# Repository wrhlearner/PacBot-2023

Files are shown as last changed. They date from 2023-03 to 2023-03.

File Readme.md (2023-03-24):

# **Schedule**

## **Directions**

- Hardware: 
  - Axel: Teensy4.0, Magnetic encoder, Motor driver, Motor
  - Jack: RaspberryPi, Motor driver, IR sensors
- Software: 
  - Ines: Server side
  - Jack: GameEngine host side and RaspberryPi

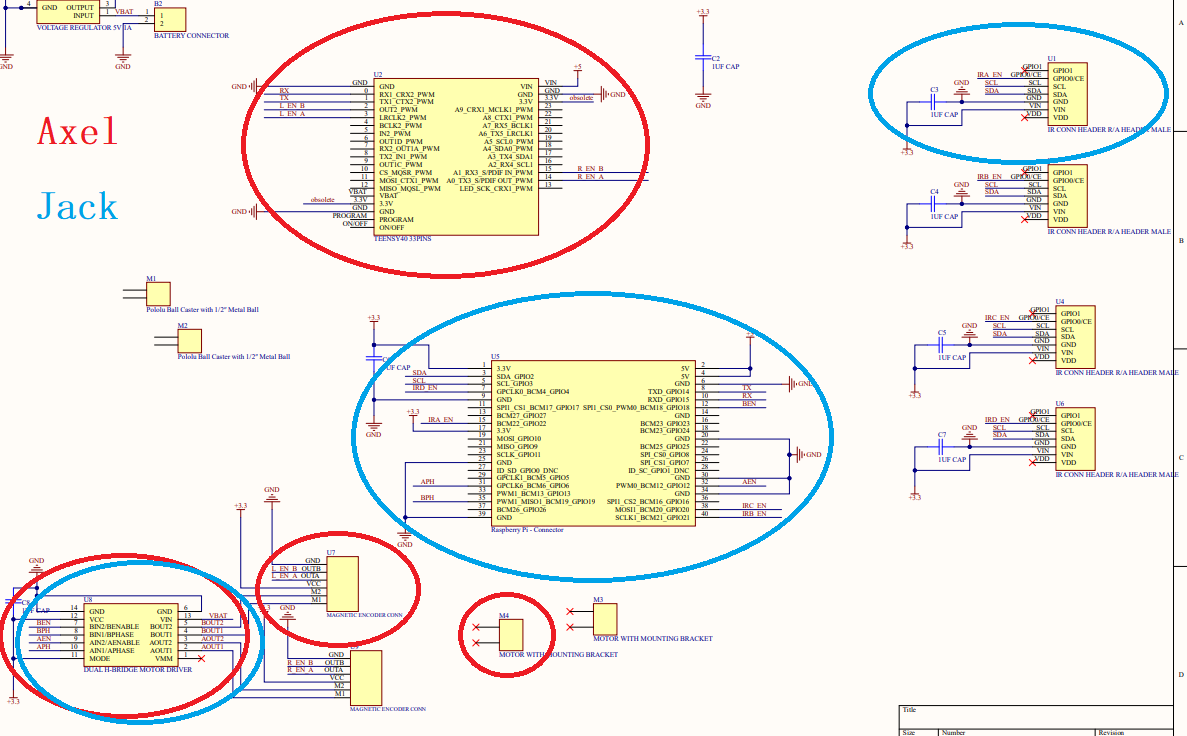
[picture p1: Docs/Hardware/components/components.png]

For the hardware, refer to [our PCB schematic](./Docs/Hardware/Altium/PacBot.pdf) for component connections.

## **Reference**
[2022 UCLA Micromouse tutorial](https://www.youtube.com/watch?v=UHWE3d_au30&list=PLAWsHzw_h0iiPIaGyXAr44G0XfHfyjOe7): mechanisms about components we will use, including battery/power, motors, magnetic encoders, PID control, IR sensors, and PCB design tips. Suggest to watch Lecture 1 Battery Safety and Usage (4:24-6:37) before touching the LiPo batteries. It will literally explode.

[RaspberryPi Datasheets](https://datasheets.raspberrypi.com/)

[Beginners Guide to LiPo Batteries for FPV Drones](https://fpvfc.org/beginners-guide-to-lipo-batteries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,a%20battery%20bursting%20into%20flames.)

[L7805 voltage regulator](https://www.mouser.com/ProductDetail/STMicroelectronics/L7805ACD2T-TR?qs=Ctxo64yJVFuOLXlPPZdJUQ%3D%3D)

[50:1 Micro Metal Gearmotor MP 6V with Extended Motor Shaft](https://www.pololu.com/product/2379/resources)

[Teensy 4.0](https://www.pjrc.com/store/teensy40.html)

[DRV8835 motor driver](https://www.pololu.com/product/2135)

[Magnetic encoder](https://www.pololu.com/product/3081)

[VL6180X IR sensor](https://www.pololu.com/product/2489)

[Altium Designer PCB Design Tutorial for Beginners (v20 and 21)](https://www.youtube.com/watch?v=KpgRl28C018&list=PLDclr_SCaTAxEpaE0uf9RDQUNtW5YSoxW)

## **Timeline**

[X] Week 1: Mar 6 - Mar 12

[X] Week 2: Mar 12 - Mar 19

[X] Week 3: Mar 19 - Mar 26

<font color='red'>Hardware prototype ddl</font>

[ ] Week 4: Mar 26 - Apr 2

[ ] Week 5: Apr 2 - Apr 9

<font color='red'>Running PacMan ddl</font>

[ ] Week 6: Apr 9 - Apr 16

[ ] Week 7: Apr 16 - Apr 23

<font color='red'>Testing ddl</font>

<font color='red'>Competition: Apr 23</font>

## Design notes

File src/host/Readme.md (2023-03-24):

**Tasks**

March 27 - April 2

[ ] Build decision algorithms, e.g. decision tree, reinforcement learning, etc., to generate movement command for PacBot

[ ] Build WiFi communication code between RPY and host

[ ] Build PID control code on RPY

April 2 - April 9

[ ] Build code on the host computer to receive game status from server

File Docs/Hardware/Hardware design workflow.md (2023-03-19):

# **Hardware design workflow**

[toc]

## **1 Circuit and Mechanical Design**

### **1.1 Batteries and Voltage Regulator**

### **1.2 Motor, Motor Driver, and Encoder**

### **1.3 PID Control**

### **1.4 IR Sensors and IMU Sensor**

### **1.5 Circuit Design**

### **1.6 Mechanical Design**

## **2 Component Searching and Schematic**

> component search sources
>
> - [LCSC](https://www.lcsc.com/)
> - [DigiKey](https://www.digikey.com/)
> - Mouser
> - Adafruit
> - Sparkfun

### **2.1 Microcontroller**

### **2.2 WiFi Module**

### **2.3 Other Parts**

### **2.4 Circuit Design**

## **3 CAD Schematic**

> CAD tools
>
> - [EasyEDA](https://easyeda.com/)

3.1 Build Design Library

3.1.1 create schematic symbol

3.1.2 create PCB footprint

3.1.3 bind and create 3D model for footprint

3.1.4 find components in libraries

3.2 Schematic Simulation

3.2.1 create schematic

3.2.2 Simulation library

3.2.3 LTSpice simulation

3.3 make PCB prototype

3.3.1 PCB layout

3.3.2 PCB ordering

3.3.3 PCB soldering and testing

## **4 PCB Design and Ordering**

> PCB design tools
>
> - Altium Designer
> - Cadence Allegro
> - KiCAD
>
> PCB manufacturing
>
> - [JLCPCB](https://jlcpcb.com/)

### **4.1 PCB Layout**

### **4.2 PCB Ordering**

## **5 Soldering PCB and Debug**

## **Tool Chain**

- EasyEDA

## **Reference**

- [PCB design workflow](https://www.youtube.com/watch?v=35YuILUlfGs)
- [UCLA Micromouse Tutorial](https://www.youtube.com/playlist?list=PLAWsHzw_h0iiPIaGyXAr44G0XfHfyjOe7)

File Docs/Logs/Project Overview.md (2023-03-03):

# **Log Mar 2 - Jack**

[toc]

## **1 Goal**

- understand game rules
- choose hardware parts
- choose development tool chain
- (*) codebase
- make time schedule

## **2 Tasks**

### **2.1 Game Rule**

- [Pacman game](https://freepacman.org/)

- **arena**

  - wall 4'' tall (10.16 cm)
  - [28 x 31 grid for location](https://github.com/HarvardURC/Pacbot/blob/master/src/gameEngine/pacbot/grid.py)
  - passage 7'' wide (17.78 cm)
  - the PacBots cannot exit the arena
  - given arena map
  - **Teams should be aware that due to design constraints the arena is built in three pieces, and may have small gaps or lips in the seams between the sections.** 

- **normal white dot**

  - 10 points/each
  - upon consumption, the dots vanish for the remainder of the game. 

- **4 special dots**

  > special scores: There will be 4 “special dots” that, upon collection by your PacBot, will enable the PacBot to “eat” the ghosts for extra points.

  - 50 points/each
  - 20 seconds for ghosts to avoid the PacBot
  - reach another special dot during the 20 second, 20 second avoiding time is reset
  - during the 20 seconds, PacBot can catch ghosts
    - To catch a ghost, your PacBot must enter the grid space currently occupied by the ghost.
    - scores
      - 200 points for the first ghost
      - 400 for second ghost
      - 800 for the third
      - 1600 for the fourth
    - the caught ghost will respawn in the ghost house

- **cherry**

  - 100 points
  - appear at (13, 13)
  - appear when the PacBot has eaten 70 pellets and again at 170 pellets eaten
  - disappear after 10 seconds

- **life**

  - 3 lives initially
  - start each life in its home position (position (14, 7) in arena grid).
  - At the end of each life, a “pause” signal will be sent out to your PacBot. Your PacBot **must** stop all autonomous movement at this time
  - for a ghost to catch your PacBot, it must also occupy the same grid space simultaneously.

- **Ghosts**

  - speed
    - 7''/sec or 2 grids/sec
    - <font color='red'>**may be sped up depending on the performance of the participating PacBots.**</font>
  - [action](http://gameinternals.com/understanding-pac-man-ghost-behavior)
    - 4 ghosts are independent
    - At the beginning of the game, Blinky will start just outside its home position, and approximately every 5 seconds, another ghost will exit the enclosure.
    - The ghosts are temporarily eliminated when they are caught, and will respawn at their home position.

- **end of game**

  - a team has lost all of their three lives
  - a team has collected all of the dots on the board
  - If it should be the case that the 20 second timer from a special dot still has remaining time when all the dots have been consumed, the game will end

- **win**

  1. number of points
  2. number of lives left
  3. the time taken

> **reference**
>
> - [understanding Pac-Man Ghost Behavior](http://gameinternals.com/understanding-pac-man-ghost-behavior)

### **2.2 Hardware Parts and Development Tool Chain**

past robot design: /Pacbot/docs

#### **2.3.1 Robot Design Requirements**

- **autonomous:** 
  - no human intervention in the robot’s functioning.
  - Off robot computation is allowed (i.e. your computer may run code that sends signals to your robot).
- <font color='red'>**size**</font>
  - <font color='red'>**7''x7'' grid**</font>
  - this is the minimum distance between walls, so you will likely want to build your robot smaller than this size.
  - <font color='red'>**$\le$4'' tall**</font>
- **top**
  - Each PacBot should have <font color='red'>**a flat area on top with room for a 3” diameter**</font> yellow acrylic computer vision target, which will be used for tracking the robot.
- **communication**
  - The field will have **an overhead camera** that the organizers will use **to detect the position of the PacBot** in the arena grid
  - Each robot will connect to **our server** via <font color='red'>**a socket over WiFi**</font> to receive the position of the ghosts, and other game state. A library to do this will be provided in <font color='red'>**Python**</font>. NOTE: We will <font color='red'>**not be supporting Xbee communication**</font> this year.
  - the robot must **read from the server multiple times a second** to execute "pause" movement and receive game states
  - **info from server**: an object/struct
    - The game state: paused or running
    - The position of the Pacbot in the arena grid according to the computer vision software
    - The position of each ghost in the arena grid
    - Whether each ghost is frightened
    - The Pacbot’s current score
    - The Pacbot’s remaining lives
- **movements**
  - must stay within the boundaries of the arena at all times
  -  cannot damage, adjust, move, or climb over any boundary of the arena

#### **2.3.2 Hardware and Dev Tool Chain**

- requirements

  - **size:** 7''x7''x4'' length x width x height
  - **network stacks:**
    - support WIFI
    - no Xbee communication
    - have Python API

- **default: Harvard sample hardware**

  - [electrical](https://docs.google.com/spreadsheets/d/1ZO9OBoGcNkOdx6GaBkAFo6AWodeVCOaCXKic-0er2z0/edit?usp=sharing)

  | components                            | quantity with spares | link                                                         |
  | ------------------------------------- | -------------------- | ------------------------------------------------------------ |
  | 3D Printed Materials                  | 1                    |                                                              |
  | Pololu 60mm Wheel set (yellow)        | 2                    | https://www.pololu.com/product/1422                          |
  | 1/2 in. Ball Caster (metal)           | 3                    | https://www.pololu.com/product/953                           |
  | IR Sensor                             | 8                    | https://www.pololu.com/product/2489                          |
  | Magnetic encoder pair                 | 2                    | https://www.pololu.com/product/3081                          |
  | DC Gear Motors                        | 4                    | https://www.pololu.com/product/2381                          |
  | Gearmotor Bracket                     | 2                    | https://www.pololu.com/product/989                           |
  | Li-Po Battery                         | 3                    | https://hobbyking.com/de_de/turnigy-1000mah-2s-20c-lipo-pack.html |
  | Motor Driver                          | 4                    | https://www.pololu.com/product/2135                          |
  | Voltage Regulator                     | 3                    | https://www.pololu.com/product/2851                          |
  | Diodes                                | 5                    | https://www.digikey.com/product-detail/en/MM3Z3V3B/MM3Z3V3BCT-ND/1626881 |
  | Power Transistors                     | 5                    | https://www.digikey.com/product-detail/en/MMBTA06LT1G/MMBTA06LT1GOSCT-ND/1139832 |
  | SMD LEDs                              | 25                   | https://www.digikey.com/product-detail/en/LTST-C190KSKT/160-1437-1-ND/386818 |
  | Slide Switch                          | 2                    |                                                              |
  | Assorted capacitors, resistors, wires | 1                    |                                                              |
  | IMU                                   | 1                    | https://www.adafruit.com/product/2472                        |
  | Raspberry Pi 0 W                      | 3                    | https://www.raspberrypi.org/products/raspberry-pi-zero-w/    |
  | Teensy 3.5                            | 2                    | https://www.pjrc.com/store/teensy32.html                     |
  | PCB: KiCAD                            | 3                    |                                                              |

  - Raspberry Pi Zero W
    - **802.11 b/g/n wireless LAN** WiFi
    - Bluetooth 4.1
    - Bluetooth Low Energy (BLE)
    - **1GHz, single-core CPU**
    - **512MB RAM**
    - Mini HDMI port and micro USB On-The-Go (OTG) port
    - Micro USB power
    - HAT-compatible 40-pin header
    - Composite video and reset headers
    - CSI camera connector

  - hierarchy
    - **3 PCB**: KiCAD, connecting all components
      - **microcontroller**
        - 3 raspberry Pi Zero W: run robot code using data from sensors (IR and Teensy); interface with the motors and IR sensors; receive instruction from host (high level code run on a remote computer, not on raspberry pi)

      - **power supply**
        - 3 Li-Po battery
        - 3 voltage regulator

      - **sensors**: PID control
        - 2 Teensy 3.5: receive magnetic encoder and IMU readings. Communicate these sensor data with raspberry pi via serial communication.
          - 2 magnetic encoder pair: track the amount of distance we travel.
          - 1 IMU: An IMU was intended to be used for general navigation of the robot (to ensure we don't hit walls and turn accurately - other uses are possible)
        - 8 IR sensors: IR sensors are used for detecting whether we are near walls. These are placed on the sides and the front/back of the bot

      - <font color='red'>**motors**</font>
        - 4 motor driver: A motor driver is necessary to communicate with the motors from the Raspberry Pi
          - 4 DC gear motors: 6V brushed DC gear motors

    - **Mechanical**: SolidWorks
      - 1 3D Printed Materials
      - 2 60mm wheel set
      - 1/2'' ball caster

    - **others**
      - 2 gearmotor bracket
      - 5 diodes
      - 5 power transistors
      - 25 SMD LEDs
      - 2 slide switch
      - 1 assorted caps, res, wires

- **UCLA micromouse sample**

> reference:

- components

  - development board

    | Board       | IDE                                                          | size | network stacks | Python API | RL   | power module | motor | sensor |
    | ----------- | ------------------------------------------------------------ | ---- | -------------- | ---------- | ---- | ------------ | ----- | ------ |
    | RaspberryPi |                                                              |      |                |            |      |              |       |        |
    | STM32       | STM32CubeIDE<br />STM32CubeMX<br />GCC<br />ST-LINK Debugger |      |                |            |      |              |       |        |
    | Arduino     |                                                              |      |                |            |      |              |       |        |

    Types of Microcontrollers

    | Microncontroller | RAM  | ROM  | clock rate | supply power | interfaces |
    | ---------------- | ---- | ---- | ---------- | ------------ | ---------- |
    |                  |      |      |            |              |            |
    |                  |      |      |            |              |            |
    |                  |      |      |            |              |            |

  - power supply

  - motor

  - sensors

  - reinforcement learning (RL) deployment

#### **2.3.3 Test env - Arena design**

refer to arena design in [Github public design](https://github.com/HarvardURC/Pacbot/tree/master/docs/Arena%20Documentation)

- design tools: SolidWorks

### **2.4 Software Code Base**

[Github Repo](https://github.com/HarvardURC/Pacbot)

#### **2.4.1 Pacman Game Code - host**

/Pacbot/src/gameEngine

#### **2.4.2 Bot Code - PacBot**

/Pacbot/src/botCode

#### **2.4.3 server**

#### **2.4.4 Communication**

/Pacbot/docs

[How to run the game and connect to your bot - A Guide](https://github.com/HarvardURC/Pacbot/blob/master/docs/A%20Guide%20to%20Connecting%20to%20the%20Game.md)

- 1 server, 1 host, 1 robot
- how does robot receive game status? server -> host -> robot via WIFI

### **2.5 Time Schedule**

- Week 1: Mar 6 - Mar 12
- Week 2: Mar 12 - Mar 19
- Week 3: Mar 19 - Mar 26

Hardware prototype ddl

- Week 4: Mar 26 - Apr 2
- Week 5: Apr 2 - Apr 9

Running PacMan ddl

- Week 6: Apr 9 - Apr 16
- Week 7: Apr 16 - Apr 23

Testing ddl

Competition: Apr 23

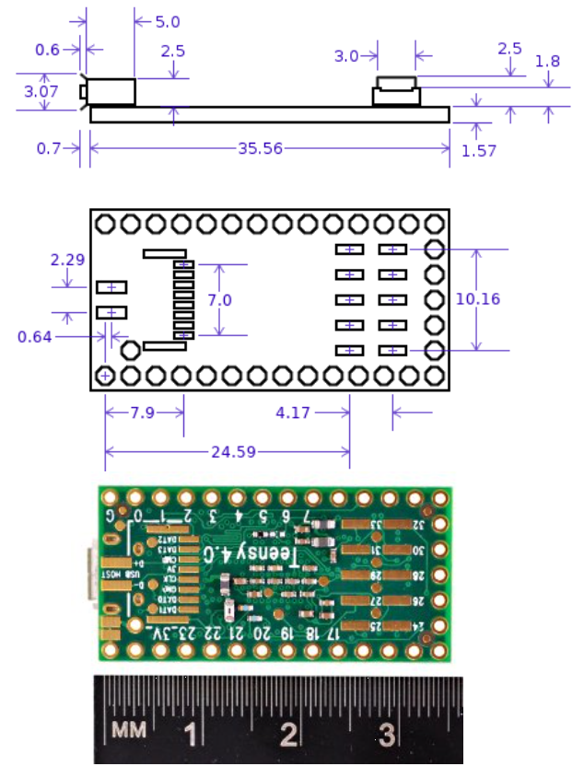
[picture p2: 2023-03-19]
Docs/Hardware/components/Teensy40/mechanical dimensions back side.png

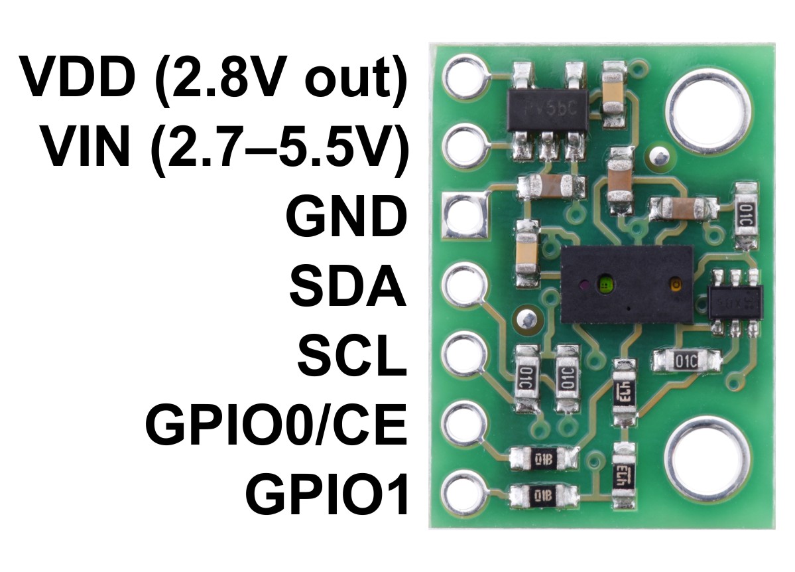
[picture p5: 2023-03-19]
Docs/Hardware/components/IR/Pinout diagram.jpg

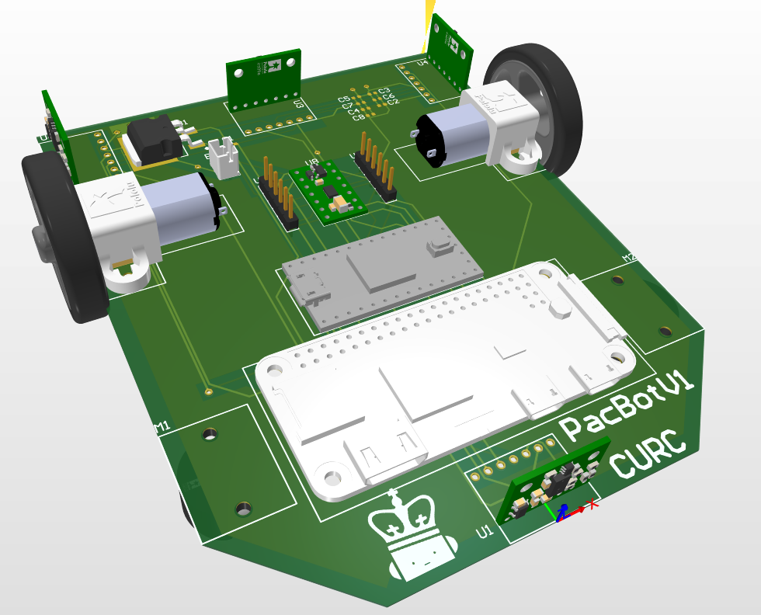
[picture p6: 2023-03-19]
Docs/Hardware/PCB/3D model front.png

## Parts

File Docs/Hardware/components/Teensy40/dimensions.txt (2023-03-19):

https://www.pjrc.com/store/teensy40.html#tech

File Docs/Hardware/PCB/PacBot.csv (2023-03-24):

Comment | Description | Designator | Footprint | LibRef | Quantity | Additional Material | Additional Material Link | Product URL
VOLTAGE REGULATOR 5V 1A | Voltage Regulator 5V 1A D2PAK STMicroelectronics L78xx L7805ACD2T-TR, Single Linear Voltage Regulator, 1.5A 5 V, +/-2%, 3-Pin D2PAK | B1 | D2PAK-STB35NF10T4 | L7805ACD2T-TR | 1 | None | None | https://www.mouser.com/ProductDetail/STMicroelectronics/L7805ACD2T-TR?qs=Ctxo64yJVFuOLXlPPZdJUQ%3D%3D
BATTERY CONNECTOR | HPI Series; 2mm Pitch 2 Way 1 Row Straight PCB Header; Solder Termination; 3A | B2 | TE_440054-2 | 440054-2 | 1 | 2xfemale dupont wire | https://www.pololu.com/category/298/ribbon-cable-premium-jumper-wires | https://www.te.com/usa-en/product-440054-2.html
1UF CAP | SMD Capacitor X5R(EIA) with Capacitance: 1.0uF Tol. 10%. Rated Voltage: 6.3Vdc | C1, C2, C3, C4, C5, C6, C7, C8 | CAPC1608X90N | GRM188R60J105KA01D | 8 | None | None | https://www.digikey.com/en/products/detail/GRM188R60J105KA01D/490-1550-1-ND/587755?curr=usd
Pololu Ball Caster with 1/2¡å Metal Ball | This ball caster uses a 1/2¡å diameter metal ball. The height of the assembled kit ranges from 0.5¡å to 0.8¡å, depending on the combination of included spacers used. | M1, M2 | Ball_Caster | Ball_Caster | 2 | 2*M2 screws and nuts for each ball caster | None | https://www.pololu.com/product/953/resources
MOTOR WITH MOUNTING BRACKET |  | M3, M4 | MOTOR | MOTOR | 2 | Pololu Micro Metal Gearmotor Bracket Pair - Black | https://www.pololu.com/product/989/resources | https://www.pololu.com/product/2379/resources
IR CONN HEADER R/A HEADER MALE | This sensor is a carrier/breakout board for ST¡¯s VL6180X proximity and ambient light sensor, which measures the range to a target object up to 20 cm away (or 60 cm with reduced resolution). The VL6180X uses time-of-flight measurements of infrared pulses for ranging, allowing it to give accurate results independent of the target¡¯s color and surface. Distance and ambient light level measurements can be read through a digital I2C interface. The board has a 2.8 V linear regulator and integrated level-shifters that allow it to work over an input voltage range of 2.7 V to 5.5 V, and the 0.1¡å pin spacing makes it easy to use with standard solderless breadboards and 0.1¡å perfboards. | U1, U3, U4, U6 | VL6180X | VL6180X | 4 | 7-Pin R/A Male headers per IR | https://www.digikey.com/en/products/detail/adam-tech/PH1RB-14-UA/9831063 | https://www.pololu.com/product/2489/resources
TEENSY40 33PINS | Teensy USB Board, Version 4.0. 32 bits arduino compatible microcontroller | U2 | TEENSY40 | TEENSY40 | 1 | 33-Pin male headers per Teensy | https://www.pololu.com/product/965 | https://www.pjrc.com/store/teensy40.html
Raspberry Pi - Connector | RASPBERRYPI GPIO MALE HEADER | U5 | RPY | RPY | 1 | 40-Pin RaspberryPi GPIO header per PI | https://www.digikey.com/en/products/detail/PRT-14275/1568-1675-ND/7428264?curr=usd | https://www.raspberrypi.com/products/raspberry-pi-zero-w/
MAGNETIC ENCODER CONN | THT Vertical Pin Header WR-PHD, Pitch 2.54 mm, Single Row, 6 pins | U7, U9 | 61300611121 | CMP-1502-01070-1 | 2 | 6*female dupont wire per header | https://www.pololu.com/category/298/ribbon-cable-premium-jumper-wires | https://www.digikey.com/en/products/detail/w%C3%BCrth-elektronik/61300611121/4846833
DUAL H-BRIDGE MOTOR DRIVER | Texas Instruments¡¯ DRV8835 is a tiny dual H-bridge motor driver IC that can be used for bidirectional control of two brushed DC motors at 0 V to 11 V. | U8 | DRV8835 | DRV8835 | 1 | 2*7-pin 0.1'' male headers per unit | https://www.pololu.com/product/965 | https://www.pololu.com/product/2135/specs

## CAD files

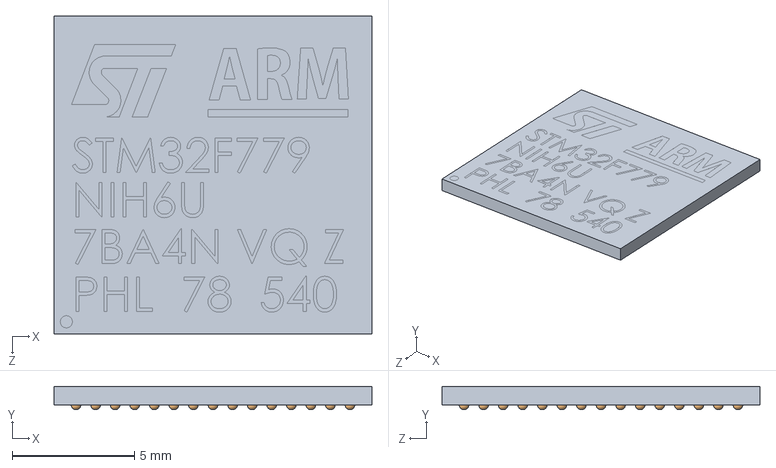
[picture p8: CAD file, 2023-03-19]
Docs/Hardware/components/Teensy40/Teensy_4.0/STM32F779NIHx.SLDASM
13.0 x 0.96 x 13.0 mm
ball x 216

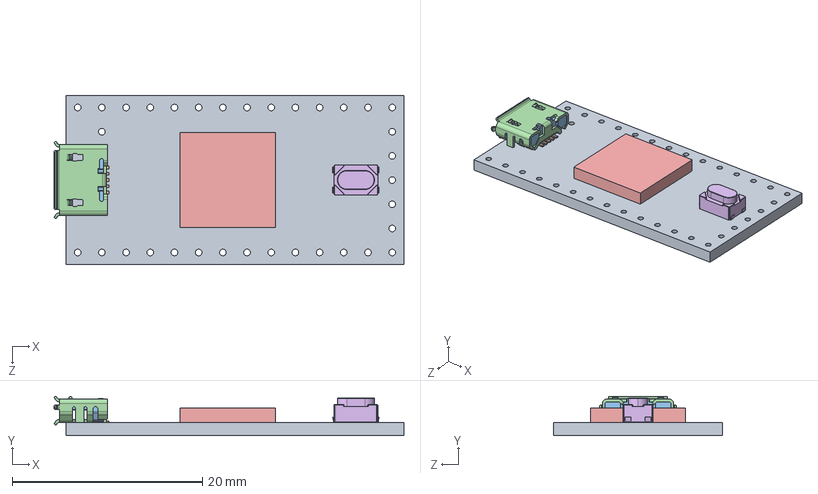
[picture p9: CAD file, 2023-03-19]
Docs/Hardware/components/Teensy40/Teensy_4.0/Teensy_4.0_Assembly.STEP
36.8 x 4.12 x 17.7 mm
Teensy_4.0_PCB
Micro USB-B Female 5Pin SMD
NXP iMXRT1062
SKRPACE010 v4

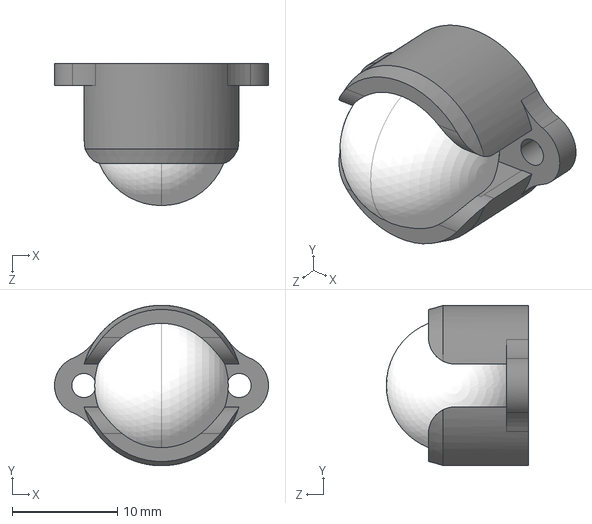
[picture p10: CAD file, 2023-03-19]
Docs/Hardware/components/ball caster/pololu-ball-caster-with-0-500in-ball.step
20.3 x 15.2 x 13.5 mm

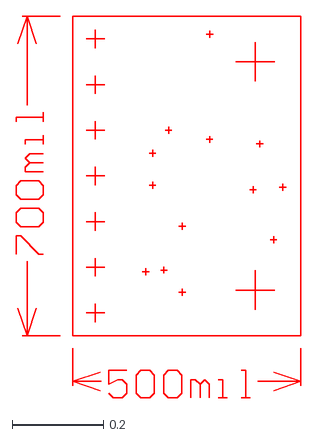
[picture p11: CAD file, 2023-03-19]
Docs/Hardware/components/IR/irs09a-drill.dxf
0.624 x 0.836

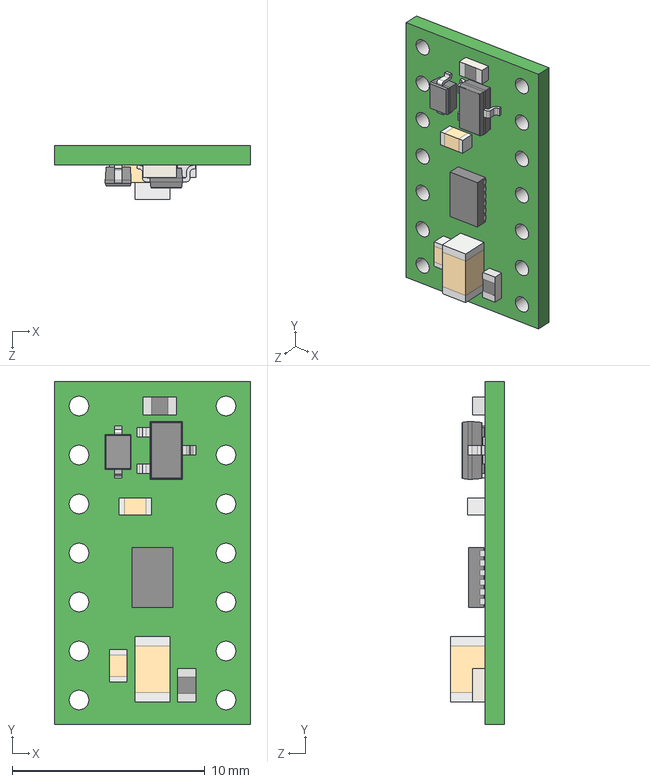
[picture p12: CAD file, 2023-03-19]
Docs/Hardware/components/motor driver/drv8835-dual-motor-driver-carrier.step
10.2 x 17.8 x 2.82 mm

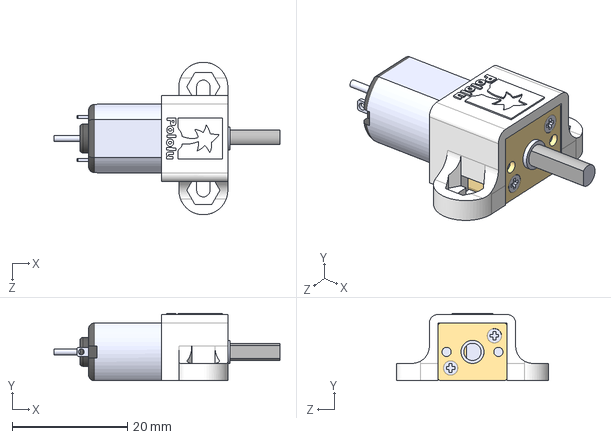
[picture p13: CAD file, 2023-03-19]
Docs/Hardware/components/motor/micro-metal-gearmotor-extended-with-1086-bracket.step
39.3 x 11.7 x 26.5 mm

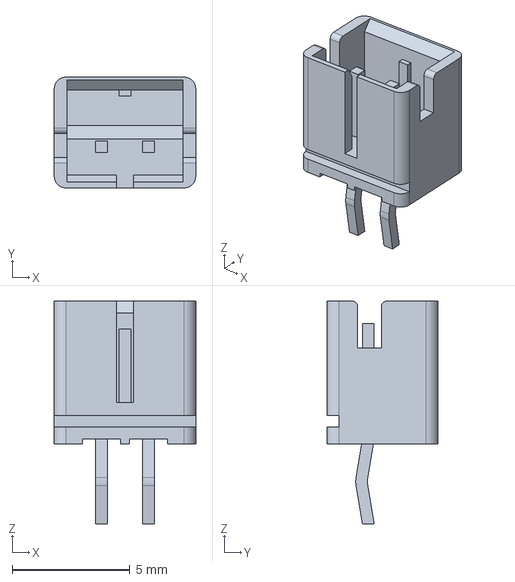
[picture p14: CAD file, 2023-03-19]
Docs/Hardware/components/power supply/battery connector/c-440054-2-f4-3d.stp
6.00 x 4.70 x 9.45 mm

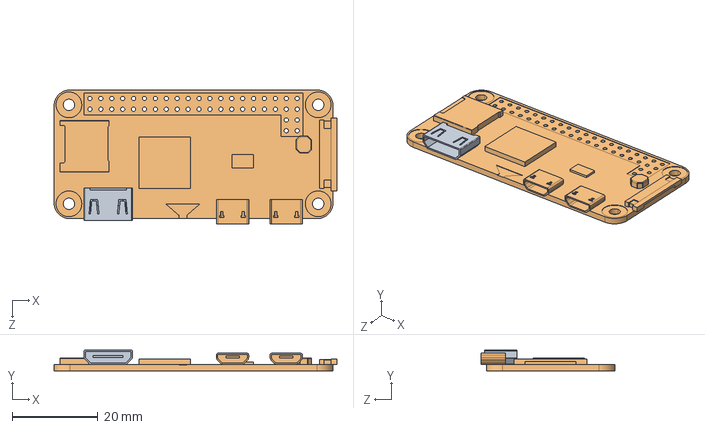
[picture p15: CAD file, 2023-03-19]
Docs/Hardware/components/RPY/RaspberryPiZeroW.STEP
65.9 x 4.80 x 31.2 mm

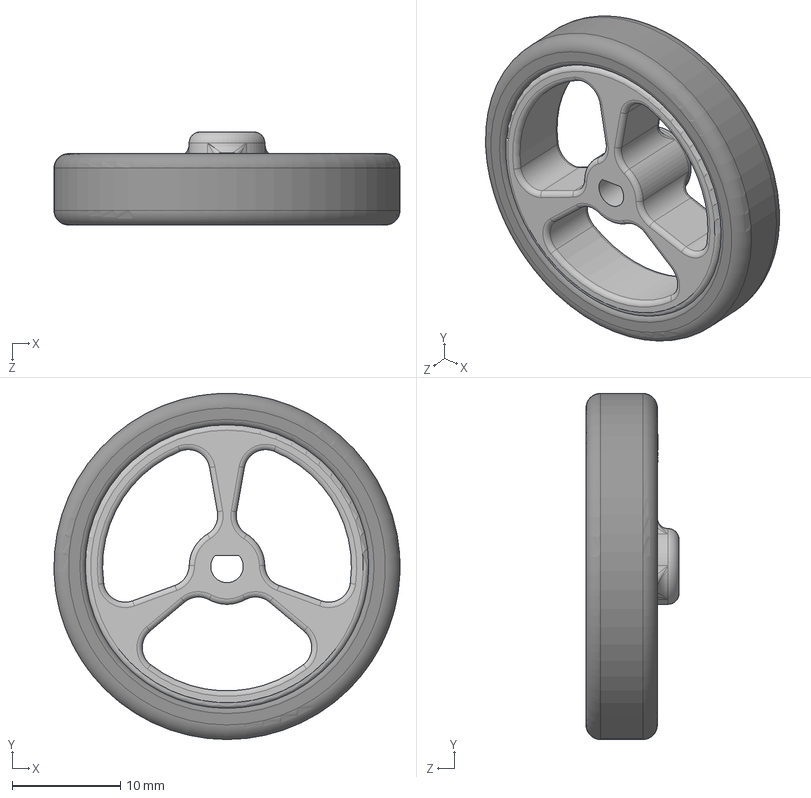
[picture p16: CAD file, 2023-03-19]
Docs/Hardware/components/wheels/pololu-wheel-32x7mm-black.step
32.0 x 32.0 x 8.60 mm

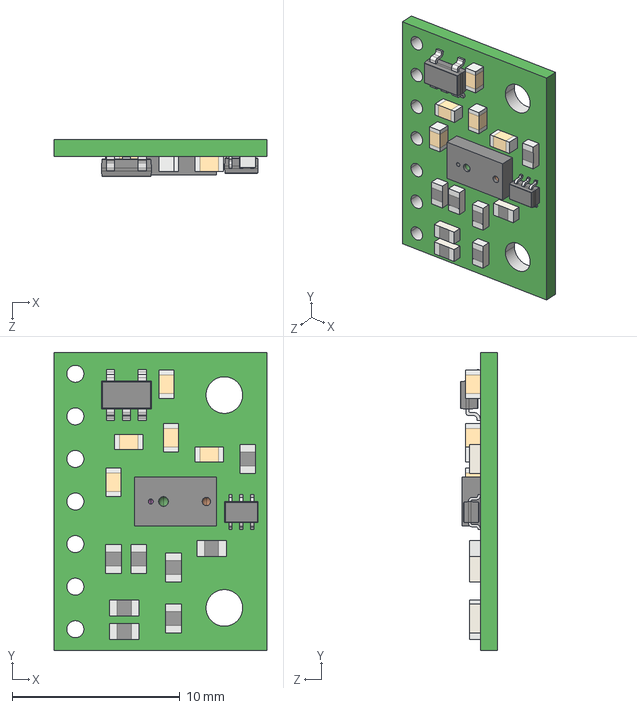
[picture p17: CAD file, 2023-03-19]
Docs/Hardware/components/IR/vl6180x-carrier-model.step
12.7 x 17.8 x 2.21 mm

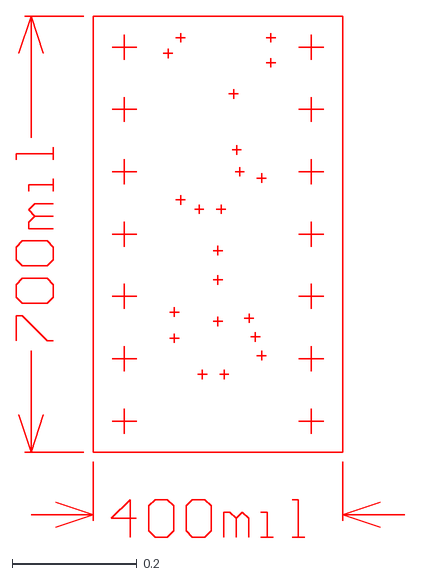
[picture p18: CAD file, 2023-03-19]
Docs/Hardware/components/motor driver/md18a-drill.dxf
0.624 x 0.836

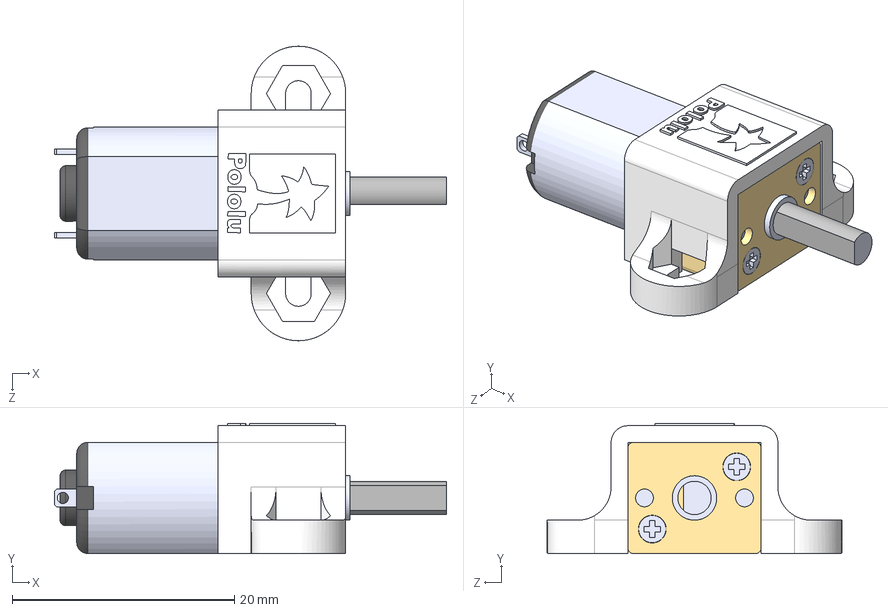
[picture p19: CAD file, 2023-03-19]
Docs/Hardware/components/motor/micro-metal-gearmotor-with-1086-bracket.step
35.3 x 11.7 x 26.5 mm

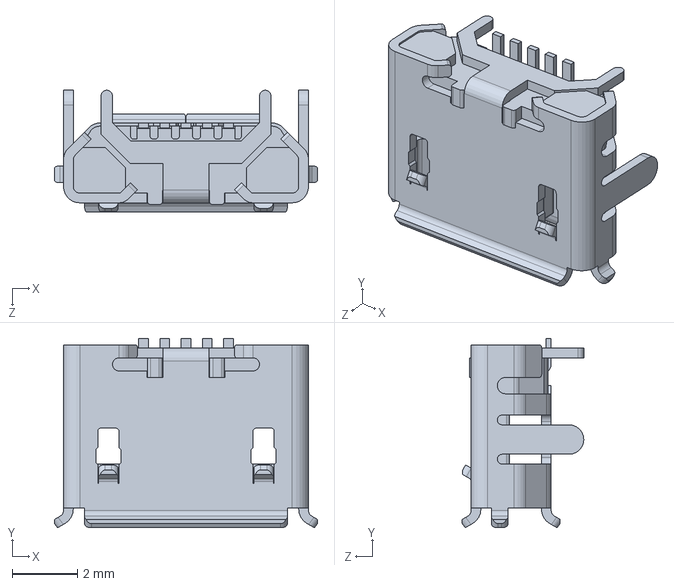
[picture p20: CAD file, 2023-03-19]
Docs/Hardware/components/Teensy40/Teensy_4.0/Micro USB-B Female 5Pin SMD.SLDPRT
8.05 x 5.80 x 3.72 mm

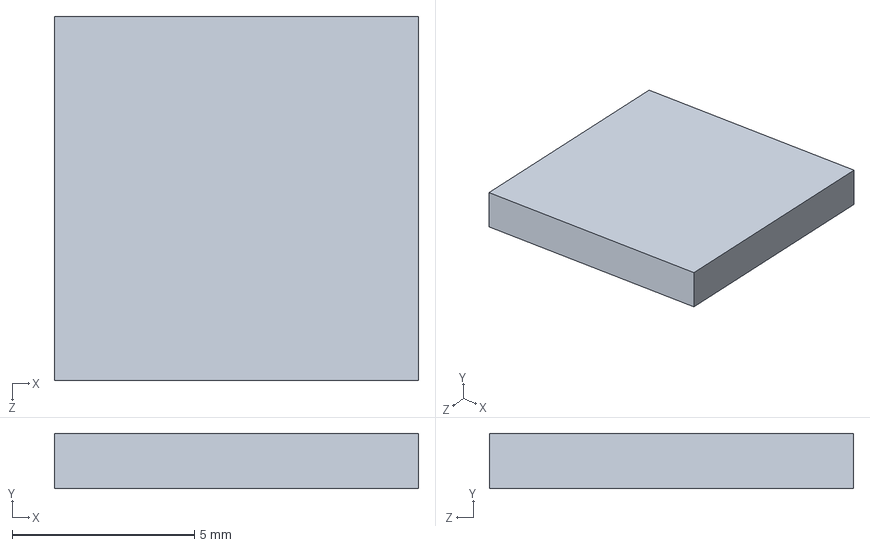
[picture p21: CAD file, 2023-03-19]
Docs/Hardware/components/Teensy40/Teensy_4.0/NXP iMXRT1062.SLDPRT
10.0 x 1.52 x 10.0 mm

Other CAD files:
Docs/Hardware/components/wheels/pololu-wheel-32x7mm-white.step
Docs/Hardware/components/Teensy40/Teensy_4.0/Teensy_4.0_PCB.SLDPRT
Docs/Hardware/components/Teensy40/Teensy_4.0/SKRPACE010 v4.SLDPRT
Docs/Hardware/components/magnetic encoder/61300611121_Download_STP_61300611121_rev1.stp
Docs/Hardware/components/RPY/RaspberryPiZeroW.IGS
Docs/Hardware/components/RPY/RaspberryPiZeroW.SLDPRT
Docs/Hardware/components/RPY/RaspberryPiZeroW.STL
Docs/Hardware/components/Teensy40/Teensy_4.0/Teensy_4.0_Assembly.SLDASM

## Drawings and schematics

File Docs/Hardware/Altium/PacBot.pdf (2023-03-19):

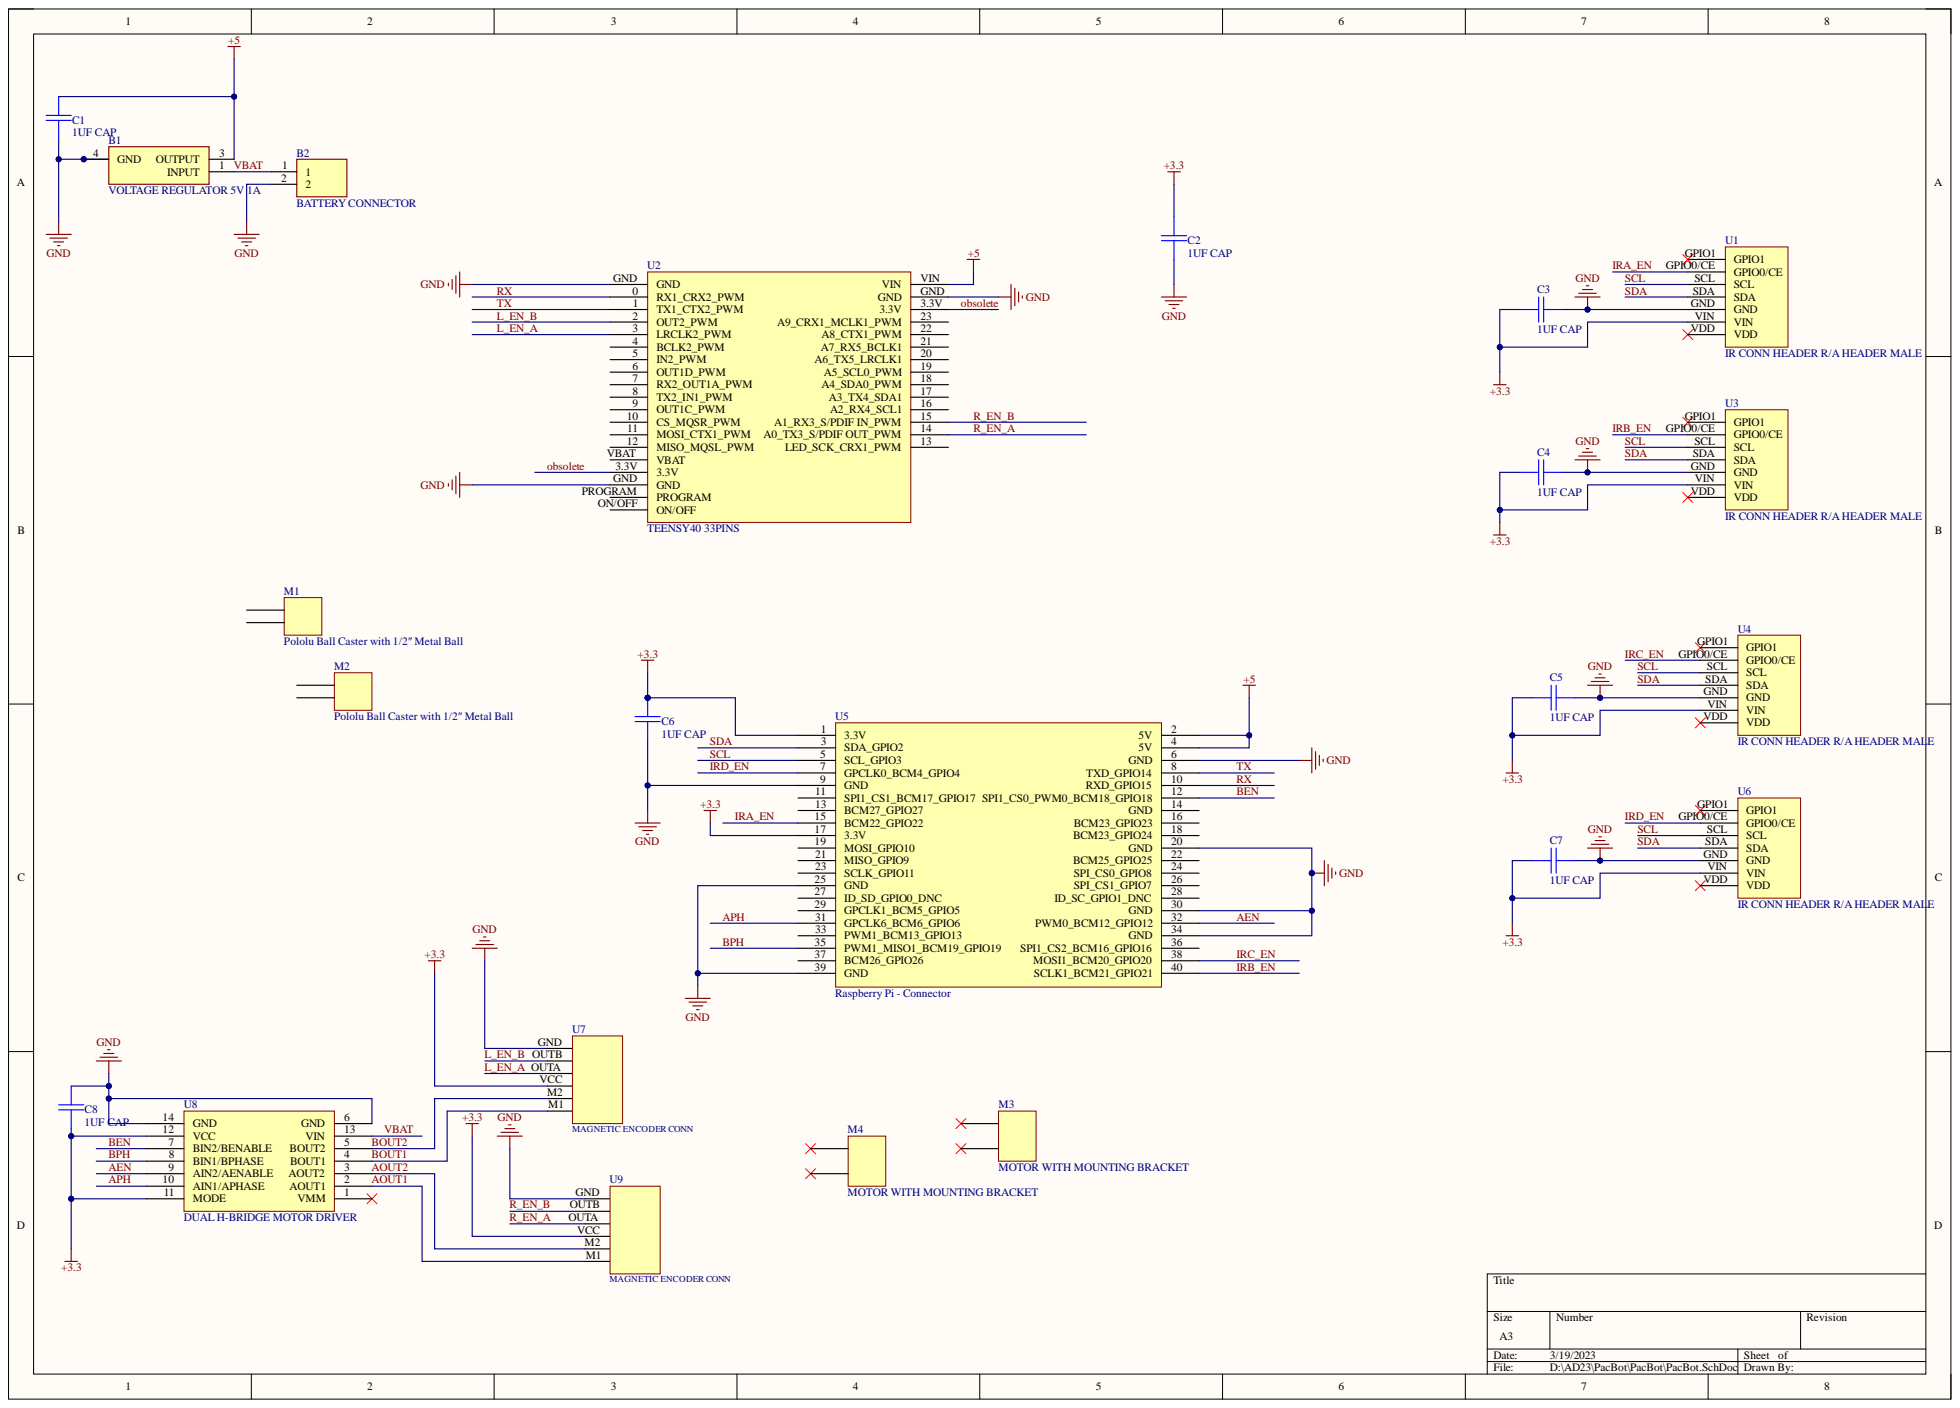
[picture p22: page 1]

IR CONN HEADER R/A HEADER MALE

Pololu Ball Caster with 1/2″ Metal Ball

VCC 12 VIN BOUT2 AOUT1 | 13 5

BOUT1
AOUT2

MOTOR WITH MOUNTING BRACKET

2 | AOUT1

DUAL H-BRIDGE MOTOR DRIVER

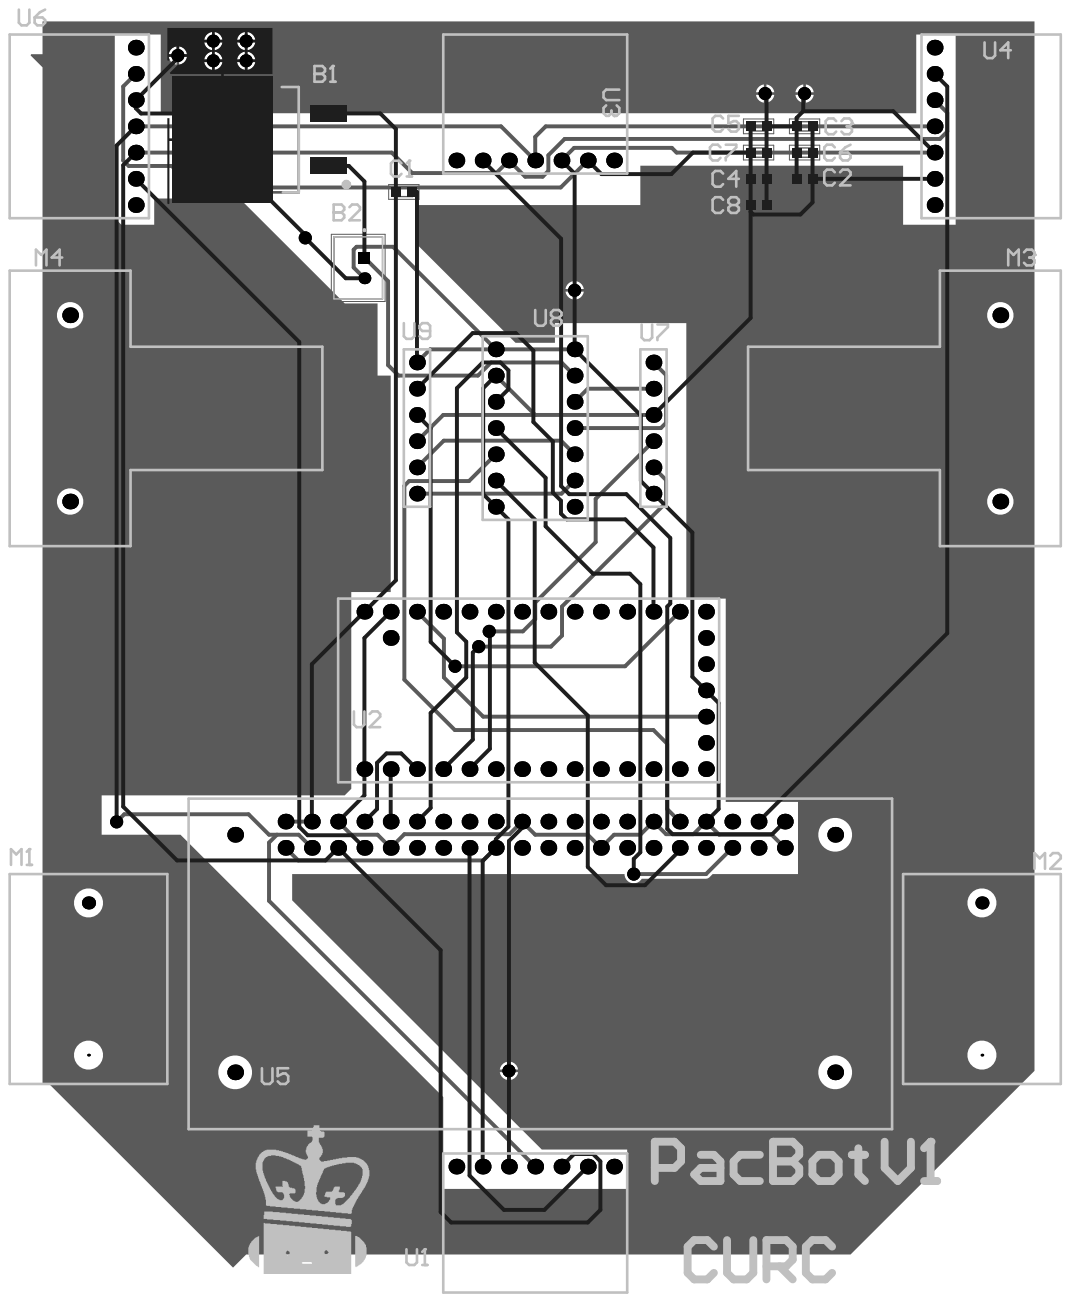
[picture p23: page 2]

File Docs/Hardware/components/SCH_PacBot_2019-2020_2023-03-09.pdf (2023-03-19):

## GND

+3V3

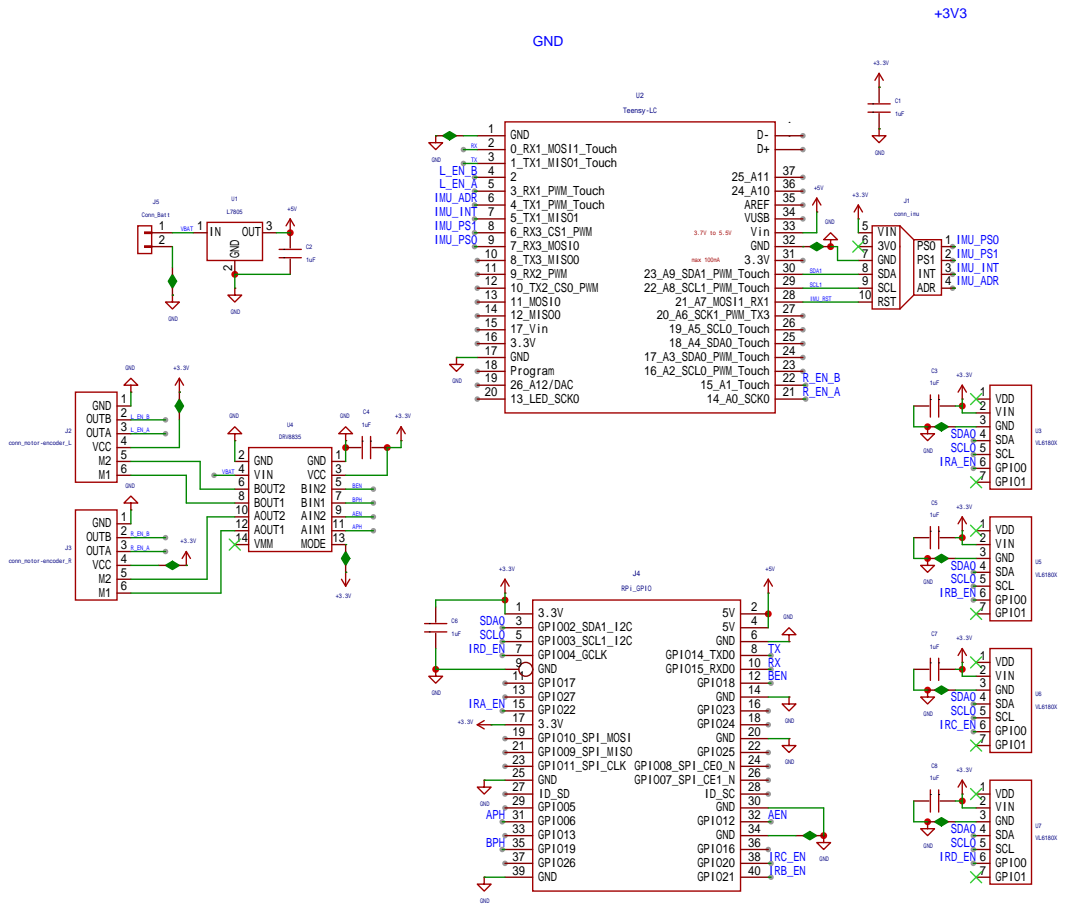
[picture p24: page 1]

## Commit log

2023-03-19 PCB design files
    [440054-2.SchLib, Components - 16.03.23 - 23.49.PcbLib, Components - 16.03.23 - 23.49.SchLib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]
2023-03-19 auto routing, DRC clean design
    [61300611121_Download_STP_61300611121_rev1.stp, PacBot.PrjPcb, PacBot.SchDoc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]
2023-03-19 add BOM csv and gerber file
    [PacBot.csv]
2023-03-24 add video reference
    [PacBot.csv]
